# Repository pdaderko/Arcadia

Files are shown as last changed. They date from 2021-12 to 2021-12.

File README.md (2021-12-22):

# Arcadia Systems arcade PCB related projects

Includes:
- 2MB Cartridge, providing similar functionality to the original "piggyback" board, plugging directly into Amiga 500 "Zorro" connector, and uses only 2x EPROMs (up to 27C080 family)
- GAL8L14 adapter, replacing original "piggyback" PAL8L14 address decoder (U3) with 2x GAL16V8 (cheaper, reprogrammable, more commonly supported, etc)
- Dumps and recreated PALs for the "piggyback" PCB
- Converter utility to decrypt/encrypt (bit swap) game ROMs for conversions

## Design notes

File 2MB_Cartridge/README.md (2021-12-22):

# Arcadia 2MB Cartridge

Functionality based on Arcadia "Piggyback" ROM board  
Attaches to 86-pin card edge on Amiga 500 motherboard  
ROM in the 0x800000-0x9DFFFF range with 2x 27C080 EPROMs  
NVRAM in the 0x9E0000-0x9FFFFF range with DS1220  
0xF00000-0xF1FFFF (address Amiga Kickstart attempts to execute) mapped to ROM (ROM offset 0x180000 to 0x19FFFF, i.e. same as addresses 0x980000-0x99FFFF)  
Uses GAL16V8 to decode addresses

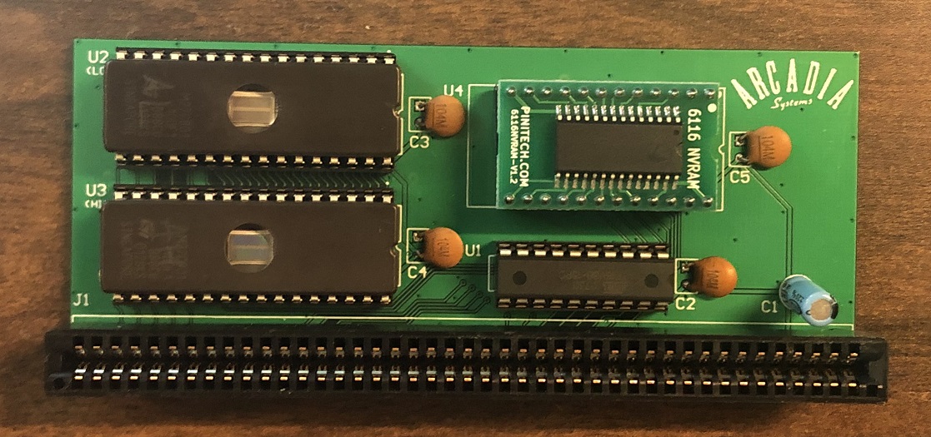
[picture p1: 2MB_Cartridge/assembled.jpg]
assembled


Notes:  
NVRAM seems to need 150ns or faster  
-original cartridge used DS1220Y-150  
-DS1220Y-200 causes glitches on both new cartridge and original "Piggyback"  
-FRAM based 6116 NVRAM seems to work fine  
See ROM directory for notes on building EPROM images

Tested with female card edge connector: TE P/N 1-5530843-0, though I expect it would work with EDAC P/N 345-086-540-201 or 345-086-520-202, or other 86-pin 0.1" female card edge connectors compatible with 0.062" thick PCBs.

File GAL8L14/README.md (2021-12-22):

# GAL8L14

PCB replaces PAL8L14 with 2x GAL16V8

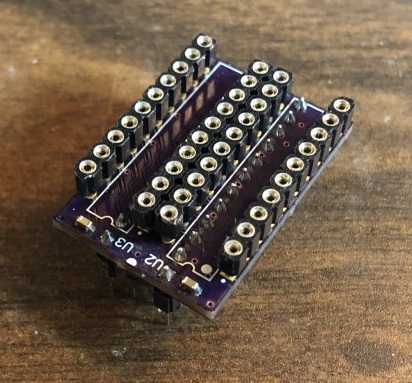
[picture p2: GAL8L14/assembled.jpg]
assembled


PAL8L14 (used on Arcadia "Piggyback" ROM board) has 8 inputs and 14 outputs, not commonly supported, and has no standard pin compatible GAL

Assembly notes:  
Install 2x 0603 capacitors at C1 and C2 if desired (decoupling caps, optional)  
Install header(s) at U1  
Install sockets at U2 and U3  

Depending on headers and sockets used, this can be done in a different order, though ensure sockets/headers won't block soldering iron access

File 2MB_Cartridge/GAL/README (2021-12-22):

Address decoder GAL for Arcadia 2MB cartridge

Signals implemented in GAL based on original "piggyback" cart signals

EP_CE (pin 12): 0 when /AS=0 and address between either 0x800000 and 0x9DFFFF (A23..A21=100 and A20..A17!=1111) or 0xF00000 and 0xF1FFFF (A23..A17=1111000), else 1
EP_A19 (pin 13): 1 when address between 0xF00000 and 0xF1FFFF (A23..A17=1111000), else A19
EP_A20 (pin 14): 1 when address between 0xF00000 and 0xF1FFFF (A23..A17=1111000), else A20
NV_CE (pin 15): 0 when /AS=0 and address between 0x9E0000 and 0x9FFFFF (A23..A17=1001111), else 1
OE (pin 16): 0 when reading (R/W=1), else 1
NV_WE (pin 17): 0 when writing (/AS=0 and R/W=0), else 1

EP_A19 and EP_A20 remaps 0xF000000-0xF1FFFF to 0x980000-0x99FFFF (Amiga Kickstart attempts to execute from 0xF000000)

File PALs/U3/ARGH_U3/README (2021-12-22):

Recreated from assumed logic equations for "piggyback" board with no BIOS (BANK1 mapped to 0x800000)
Based on dumped logic equations from SCPA BIOS board
Only known to be used for Aaargh!
This .jed file is for a PAL8L14 and is untested, though the same equations were used for the GAL replacement

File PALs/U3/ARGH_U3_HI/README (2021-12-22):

PAL8L14 converted to 2x GAL16V8 (for use with GAL8L14 adapter board)
This is the high 7 output bits
Recreated from assumed logic equations for "piggyback" board with no BIOS (BANK1 mapped to 0x800000)
Based on dumped logic equations from SCPA BIOS board
Only known to be used for Aaargh!

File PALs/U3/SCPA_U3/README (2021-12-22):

Recreated from dumped logic equations for "piggyback" board with SCPA BIOS (BIOS in BANK1 mapped to 0x980000, BANK2 mapped to 0x800000)
This .jed file is for a PAL8L14 and is untested, though the same equations were used for the GAL replacement

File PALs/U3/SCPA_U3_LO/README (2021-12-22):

PAL8L14 converted to 2x GAL16V8 (for use with GAL8L14 adapter board)
This is the low 7 output bits
Recreated from dumped logic equations for "piggyback" board with SCPA BIOS (BIOS in BANK1 mapped to 0x980000, BANK2 mapped to 0x800000)

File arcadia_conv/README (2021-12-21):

Swaps bits according to arguments to allow conversion of Arcadia games from/to any security PAL
usage: arcadia_conv <input file name> <output file name> <input shuffle> <output shuffle>

example: arcadia_conv airh_1l.bin airh_1l_bowl.bin 50247613 76012345
Converts SportTime Table Hockey ROM to run with SportTime Bowling security PAL

example: arcadia_conv airh_1l.bin airh_1l_dec.bin 50247613 76543210
Outputs SportTime Table Hockey ROM with no scramble (decrypted ROM)

Note 1: Only the first low ROM should be bit swapped, none of the other ROMs require bit swapping
Note 2: On the single game piggyback boards, only the low ROM at U16 is bit swapped.
        In the case of all games except Aaargh, this is the OnePlay BIOS (SCPA marked ROM).
        The BIOS chip is the same/compatible for all OnePlay games, so any OnePlay game can be
        converted to another OnePlay game by simply swapping unmodified ROMs.
Note 3: To use ROMs from TenPlay on OnePlay, use the appropriate input shuffle and an output
        shuffle of 76543210 (i.e. no shuffle) on the first TenPlay low ROM (U6), and place ROMs in
        sockets starting at U15 (low) and U11 (high), leaving SCPA chip in place at U16 and U12.
Note 4: Aaargh! requires a different PAL8L14 (U3) to use the appropriate memory mapping, since it doesn't
        use the OnePlay BIOS.  It's first ROM is bit swapped instead of the BIOS.

Below is a list of known bit swaps, pulled from MAME source code
SportTime Table Hockey: 50247613
SportTime Bowling: 76012345
Blastaball: 41762035
World Darts: 40763125
Magic Johnson's Fast Break: 76543210
Leader Board: 23410756 (V2.5) or 76543210 (other versions)
Ninja Mission: 16574203
RoadWars: 31640527
Sidewinder: 63452107
World Trophy Soccer: 07165432
Spot: 76543210
Space Ranger: 47306521
Xenon: 31240567
Pharaohs Match: 76543210
Delta Command: 41762035
Aaargh!: 50247613
OnePlay BIOS (SCPA): 61023457

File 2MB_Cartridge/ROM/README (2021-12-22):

27C080 EPROM maps to addresses 0x800000 to 0x9DFFFF (last 128KB of ROM is unavailable because it's mapped to NVRAM)

Original game ROMs used 27C512s (64KB of data) in a bank of LO ROMs and HI ROMs
Sets of LO ROM and HI ROM files should be concatenated from Game ROM 1 to N (where N is the number of ROMs in the ROM set, excluding the SCPA ROM if applicable).
Concatenated LO ROM file goes to position U2 and HI ROM file goes to position U3
Blank file (blank.bin) is provided for convenience to pad unused portions of the ROM with 0xFF
The ROM expected to boot must be placed in the "slot" 13 (address 0x980000).
-For SCPA games, this is the SCPA ROM
-For Aaargh!, this is the first ROM (same ROM as already in "slot" 1)
ROM(s) must be decrypted (where applicable) using the arcadia_conv utility
-Games from "piggyback" boards have SCPA LO ROM encrypted, but game ROMs unencrypted
-Exception is Aaargh!, which didn't use the SCPA ROM, and has its first LO ROM encrypted
-Games from the TenPlay boards have their first game LO ROM encrypted

Example ROM file generation commands (Windows command line using MAME ROM file names, similar functionality on Linux with "cat")

Table Hockey:
copy /b airh_1l_dec.bin + blank.bin + blank.bin + blank.bin + blank.bin + blank.bin + blank.bin + blank.bin + blank.bin + blank.bin + blank.bin + blank.bin + scpa_01-lo_v3.0_dec.u16 + blank.bin + blank.bin + blank.bin airh_2mb_lo.bin
copy /b airh_1h.bin + blank.bin + blank.bin + blank.bin + blank.bin + blank.bin + blank.bin + blank.bin + blank.bin + blank.bin + blank.bin + blank.bin + scpa_01-hi_v3.0.u12 + blank.bin + blank.bin + blank.bin airh_2mb_hi.bin

Aaargh!:
copy /b argh-1-lo-11-28-87_dec.u16 + argh-2-lo-11-28-87.u15 + argh-3-lo-11-28-87.u14 + argh-4-lo-11-28-87.u13 + argh-5-lo-11-28-87.u24 + argh-6-lo-11-28-87.u23 + argh-7-lo-11-28-87.u22 + argh-8-lo-11-28-87.u21 + argh-9-lo-11-28-87.u32 + argh-10-lo-11-28-87.u31 + argh-11-lo-11-28-87.u30 + argh-12-lo-11-28-87.u29 + argh-1-lo-11-28-87_dec.u16 + blank.bin + blank.bin + blank.bin argh_2mb_lo.bin
copy /b argh-1-hi-11-28-87.u12 + argh-2-hi-11-28-87.u11 + argh-3-hi-11-28-87.u10 + argh-4-hi-11-28-87.u9 + argh-5-hi-11-28-87.u20 + argh-6-hi-11-28-87.u19 + argh-7-hi-11-28-87.u18 + argh-8-hi-11-28-87.u17 + argh-9-hi-11-28-87.u28 + argh-10-hi-11-28-87.u27 + argh-11-hi-11-28-87.u26 + argh-12-hi-11-28-87.u25 + argh-1-hi-11-28-87.u12 + blank.bin + blank.bin + blank.bin argh_2mb_hi.bin

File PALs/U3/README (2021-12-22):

U3 is an address decoder

Files provided for original PAL8L14 as well as for GAL8L14 adapter board (using 2x GAL16V8s)

Decoder is different between SCPA games and Aaargh!
For SCPA games, it decodes the banks as follows (corresponding to silkscreen, e.g. U12 is BANK1 LO and U16 is BANK1 HI) -
BANK1:  0x980000-0x99FFFF and 0xF00000-0xF1FFFF
BANK2:  0x800000-0x81FFFF
BANK3:  0x820000-0x83FFFF
BANK4:  0x840000-0x85FFFF
BANK5:  0x860000-0x87FFFF
BANK6:  0x880000-0x89FFFF
BANK7:  0x8A0000-0x8BFFFF
BANK8:  0x8C0000-0x8DFFFF
BANK9:  0x8E0000-0x8FFFFF
BANK10: 0x900000-0x91FFFF
BANK11: 0x920000-0x93FFFF
BANK12: 0x940000-0x95FFFF
NVRAM:  0x9E0000-0x9FFFFF

For Aaargh!, it decodes the banks as follows (not a typo, the addresses shift compared to SCPA) -
BANK1:  0x800000-0x81FFFF and 0xF00000-0xF1FFFF
BANK2:  0x820000-0x83FFFF
BANK3:  0x840000-0x85FFFF
BANK4:  0x860000-0x87FFFF
BANK5:  0x880000-0x89FFFF
BANK6:  0x8A0000-0x8BFFFF
BANK7:  0x8C0000-0x8DFFFF
BANK8:  0x8E0000-0x8FFFFF
BANK9:  0x900000-0x91FFFF
BANK10: 0x920000-0x93FFFF
BANK11: 0x940000-0x95FFFF
BANK12: 0x960000-0x97FFFF
NVRAM:  0x9E0000-0x9FFFFF

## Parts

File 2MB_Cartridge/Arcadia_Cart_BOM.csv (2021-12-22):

Designator | Quantity | Comment | Install | Notes
C1 | 1 | 10uF | 10uF PTH Electrolytic Capacitor | Such as ESK106M063AC3FA
C2, C3, C4, C5 | 4 | 0.1uF | 0.1uF PTH Ceramic Capacitor | Such as C320C104K5R5TA7317
J1 | 1 | 1-5530843-0 | 86-pin 0.1” female card edge connector | 1-5530843-0 tested, 345-086-540-201 or 345-086-520-202 or other 0.1” 86-pin female card edge connectors should work as well
U1 | 1 | GAL16V8 | GAL16V8 | GAL16V8 programmed with ARC_2MB.jed file
U2, U3 | 2 | 27C080 | 27C080 | 27C080 or 27C801, or smaller EPROMs should work as well if using smaller game ROMs
U4 | 1 | DS1220 | DS1220Y-150 | Appears that this must be <150ns, FRAM based 6116 replacement seems to work as well

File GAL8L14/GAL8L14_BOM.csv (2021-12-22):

Designator | Quantity | Comment | Install | Notes
C1, C2 | 2 | 2.2uF | 2.2uF 0603 Capacitor | Optional
U1 | 1 | PAL8L14 | 24-Pin Header | Machine pin recommended (2x 12-pin SIP header OK)
U2, U3 | 2 | GAL16V8 | GAL16V8 | Programmed with appropriate U3_HI and U3_LO files, sockets recommended (machine pin SIP sockets OK)

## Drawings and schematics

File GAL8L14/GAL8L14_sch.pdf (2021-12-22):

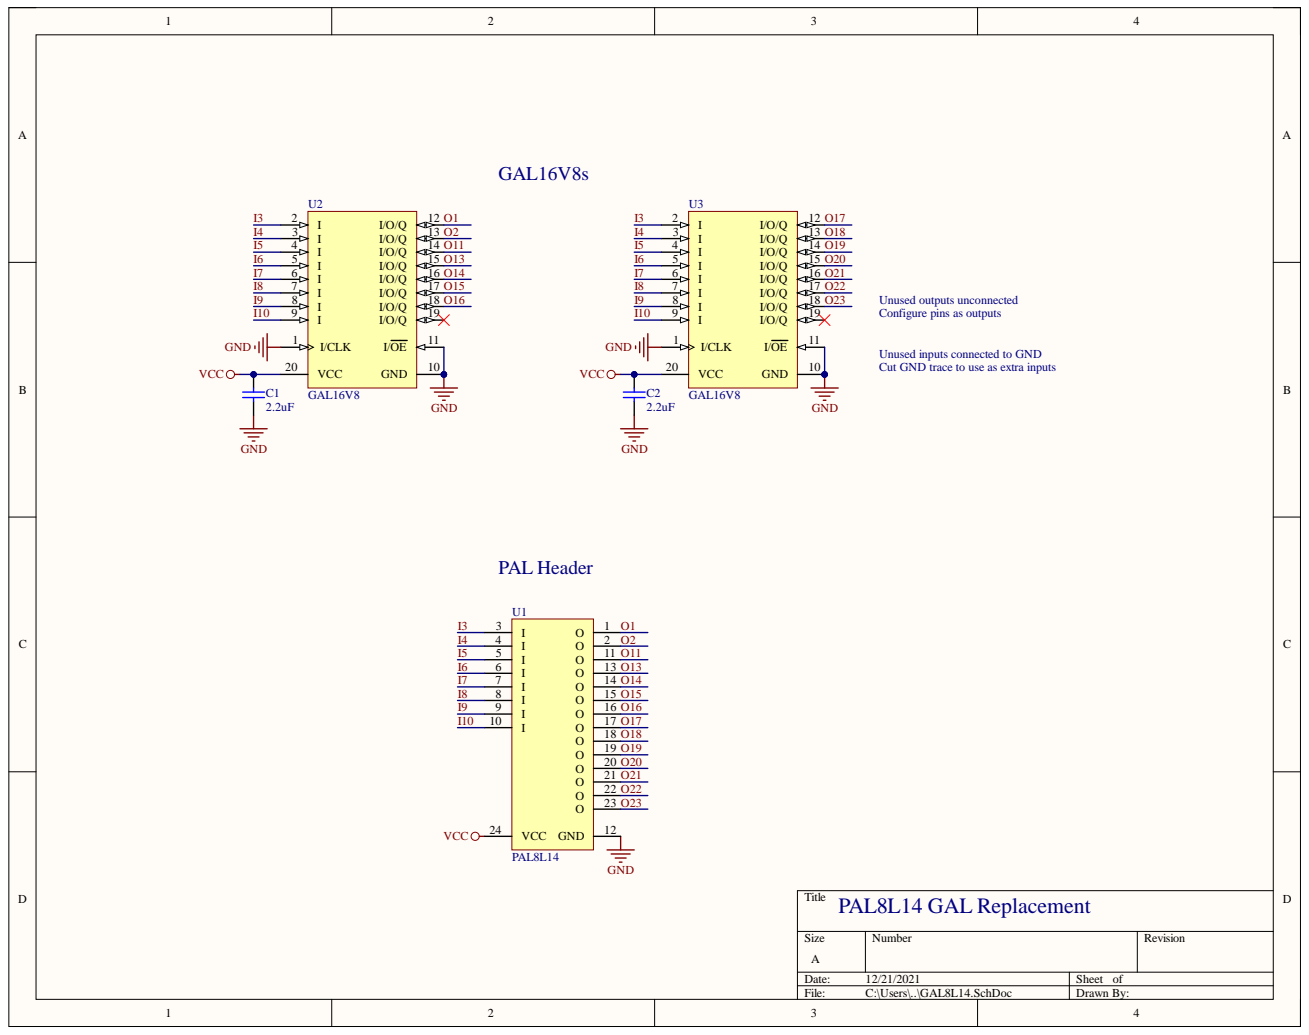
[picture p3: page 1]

Unused outputs unconnected
Configure pins as outputs

Unused inputs connected to GND
Cut GND trace to use as extra inputs

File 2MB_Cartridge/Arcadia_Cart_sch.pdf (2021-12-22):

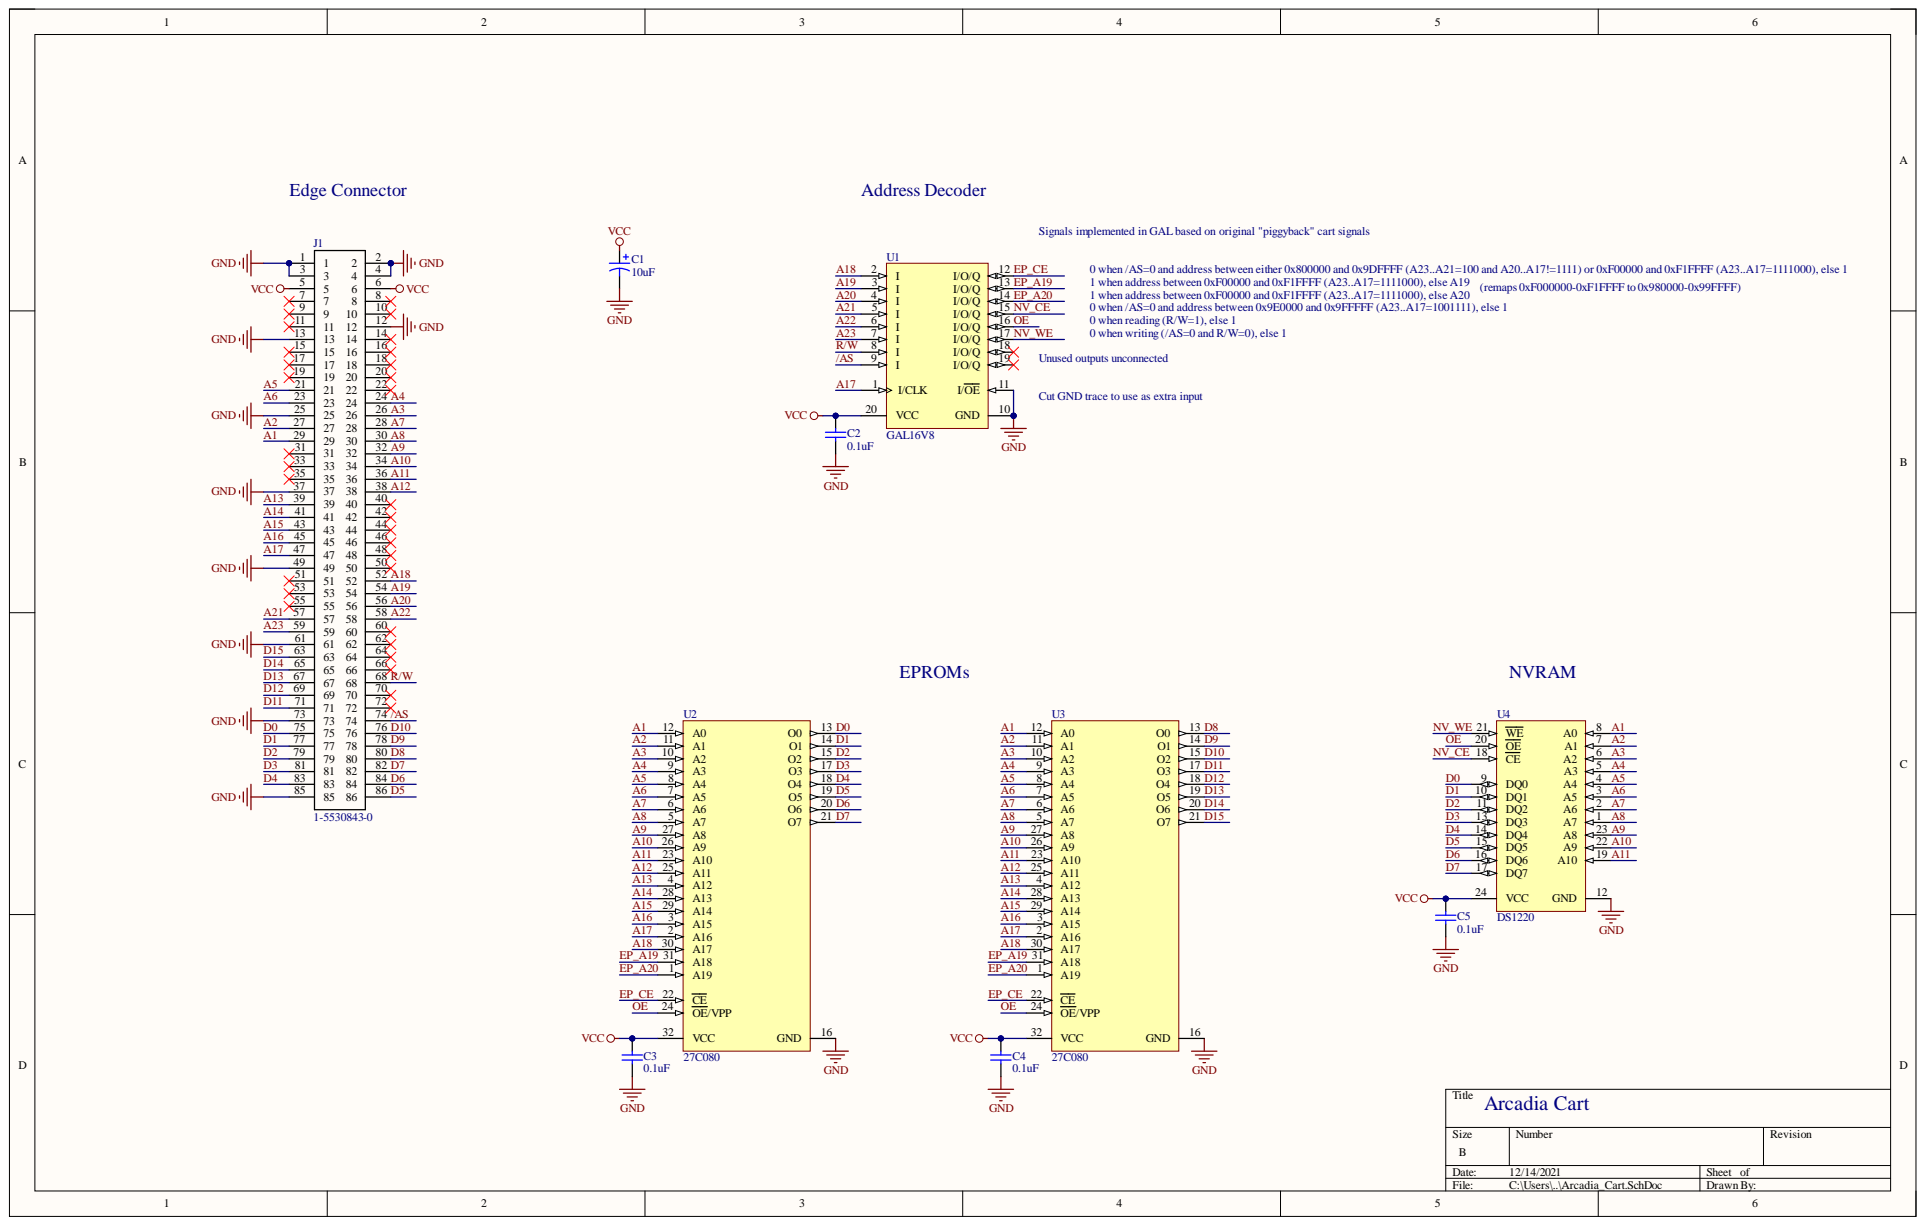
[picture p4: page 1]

Signals implemented in GAL based on original "piggyback" cart signals

0 when /AS=0 and address between either 0x800000 and 0x9DFFFF (A23..A21=100 and A20..A17!=1111) or 0xF00000 and 0xF1FFFF (A23..A17=1111000), else 1
1 when address between 0xF00000 and 0xF1FFFF (A23..A17=1111000), else A19
1 when address between 0xF00000 and 0xF1FFFF (A23..A17=1111000), else A20
0 when /AS=0 and address between 0x9E0000 and 0x9FFFFF (A23..A17=1001111), else 1
0 when reading (R/W=1), else 1
0 when writing (/AS=0 and R/W=0), else 1

Cut GND trace to use as extra input

Size B | Number | Revision

Date: 12/14/2021 | Sheet of
File: C:\Users\..\Arcadia_Cart.SchDoc | DrawnBy:

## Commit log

2021-12-22 Added 2MB Cartridge
    [Arcadia_Cart.GBL, Arcadia_Cart.GBO, Arcadia_Cart.GBS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]
2021-12-22 Added GAL8L14 files
    [GAL8L14.GBL, GAL8L14.GBO, GAL8L14.GBS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]
2021-12-22 Added Cart BOM
    [Arcadia_Cart_BOM.csv]
